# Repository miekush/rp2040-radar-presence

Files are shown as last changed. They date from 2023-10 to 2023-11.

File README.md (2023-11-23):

# RP2040 Radar Presence Sensor
RP2040/LD2410 based Radar Presence sensor

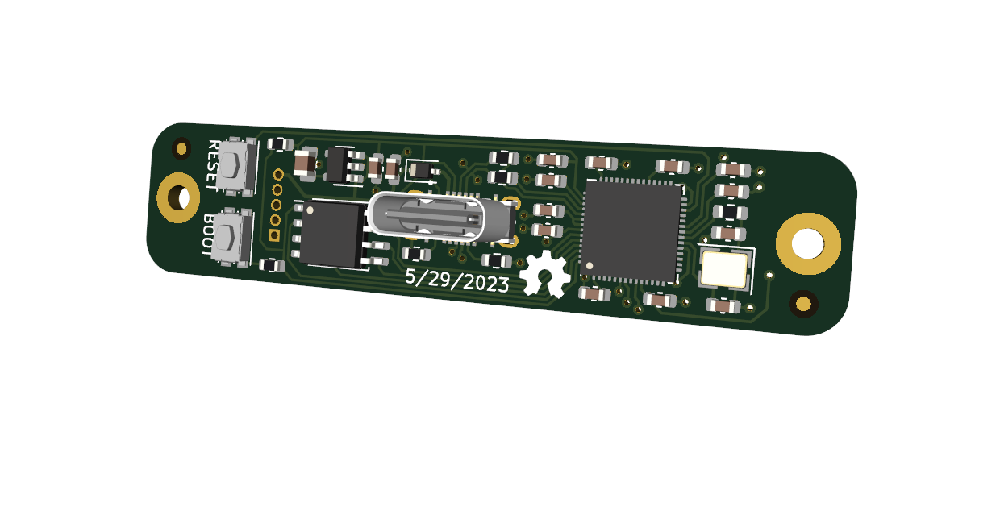
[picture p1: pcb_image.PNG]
Board Image


# Documentation

I created a short description for this project on Hackaday.io! See the project page [HERE](https://hackaday.io/project/193141-radar-halloween-candy-basket-light)!

# License

MKE supports the open source hardware community by sharing hardware design files freely on GitHub!

Please support MKE by purchasing products on [Tindie](https://www.tindie.com/stores/mkengineering/)!

Designed by Mike Kushnerik (miekush)

Licensed under [Creative Commons Attribution-ShareAlike CC BY-SA 4.0](http://creativecommons.org/licenses/by-sa/4.0/)

All text above must be included in any redistribution!

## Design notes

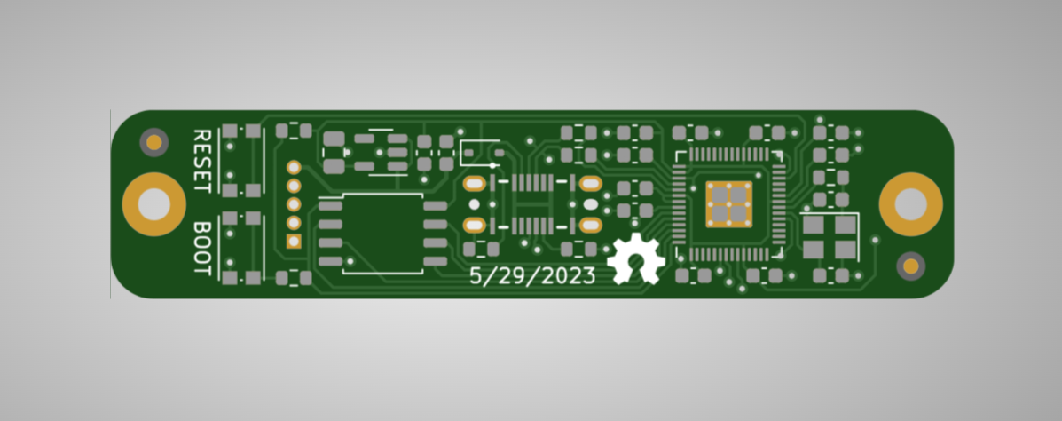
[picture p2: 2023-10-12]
pcb.PNG

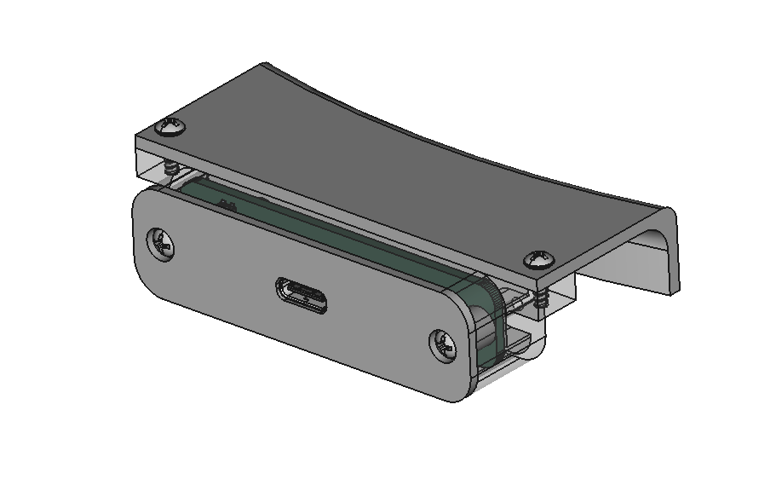
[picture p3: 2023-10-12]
enclosure/cad_image.PNG

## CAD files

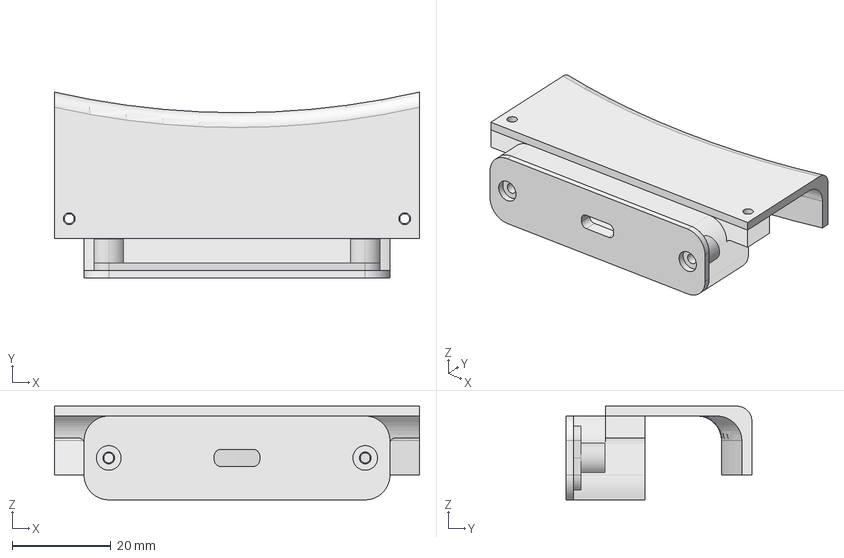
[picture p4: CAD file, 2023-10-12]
enclosure/radar_candy_bowl_light_v1.FCStd
74.0 x 37.7 x 19.0 mm
housing
cover
bracket

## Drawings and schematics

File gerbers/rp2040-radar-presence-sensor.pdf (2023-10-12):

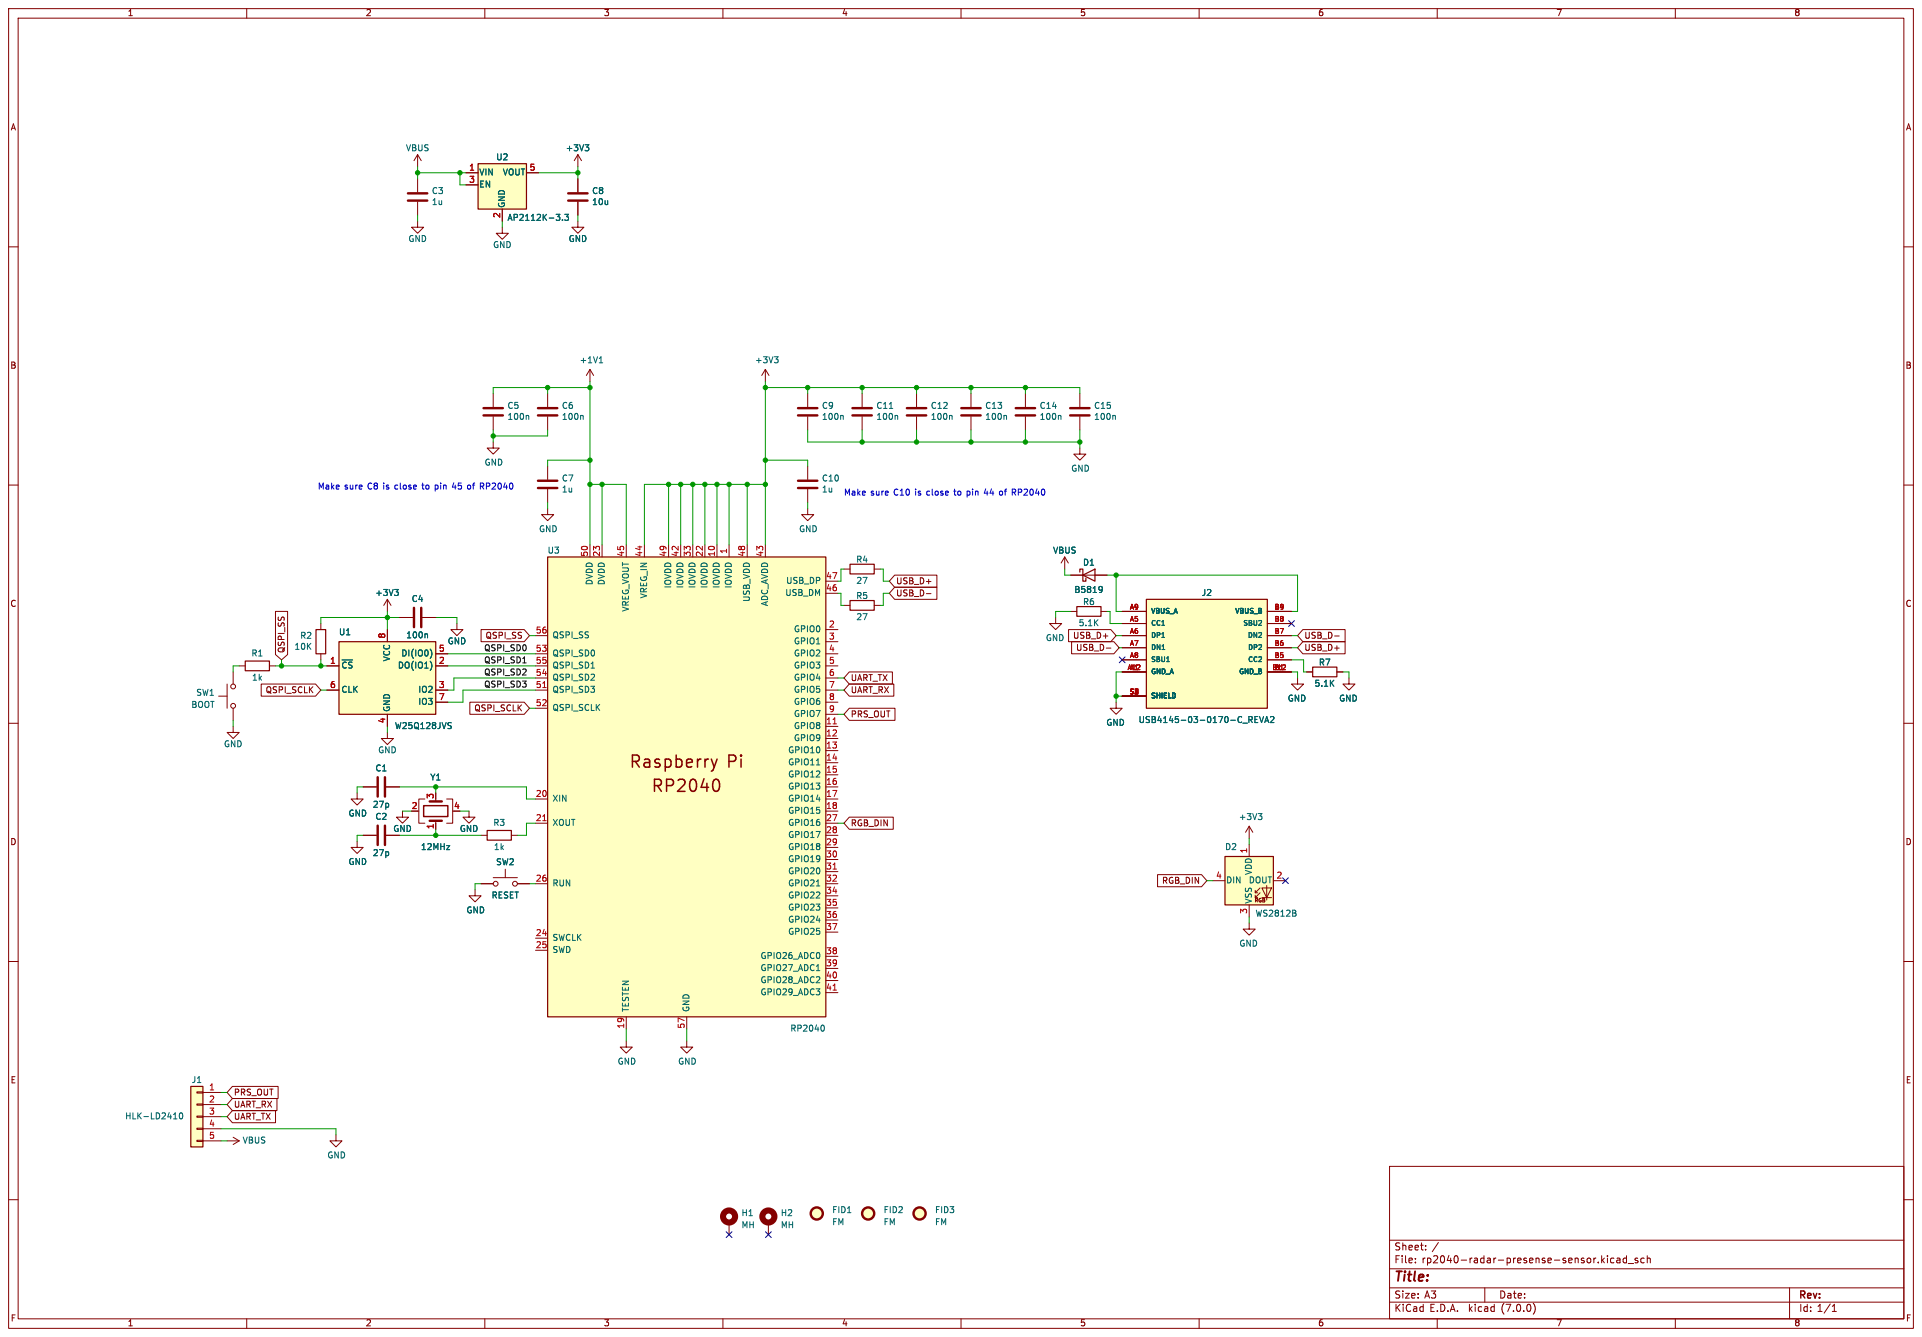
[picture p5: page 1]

1 IOVDD 10 GPIO8 11 GPIO9 12 GPIO10 13 GPIO11 14 GPIO12 15 GPIO13 16 GPIO14 17 GPIO15 18 TESTEN 19 GPIO0 2 XIN 20 XOUT 21 IOVDD 22 DVDD 23 SWCLK 24 SWD 25 RUN 26 GPIO16 27 GPIO17 28 GPIO18 29 GPIO1 3 GPIO19 30 GPIO20 31 GPIO21 32 IOVDD 33 GPIO22 34 GPIO23 35 GPIO24 36 GPIO25 37 GPIO26_ADC0 38 GPIO27_ADC1 39 GPIO2 4 GPIO28_ADC2 40 GPIO29_ADC3 41 IOVDD 42 ADC_AVDD 43 VREG_IN 44 VREG_VOUT 45 USB_DM 46 USB_DP 47 USB_VDD 48 IOVDD 49 GPIO3 5 DVDD 50 QSPI_SD3 51 QSPI_SCLK 52 QSPI_SD0 53 QSPI_SD2 54 QSPI_SD1 55 QSPI_SS 56 GND 57 GPIO4 6 GPIO5 7 GPIO6 8 GPIO7 9 U3 RP2040 GND
100n GND

Id: 1/1 Title: File: rp2040-radar-presense-sensor.kicad_sch Sheet: / GND

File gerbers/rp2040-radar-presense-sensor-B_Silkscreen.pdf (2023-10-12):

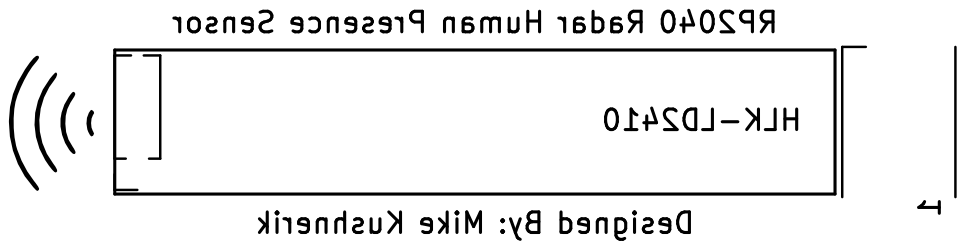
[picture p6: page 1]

HLK-LD2410 RP2040 Radar Human Presence Sensor Designed By: Mike Kushnerik 1

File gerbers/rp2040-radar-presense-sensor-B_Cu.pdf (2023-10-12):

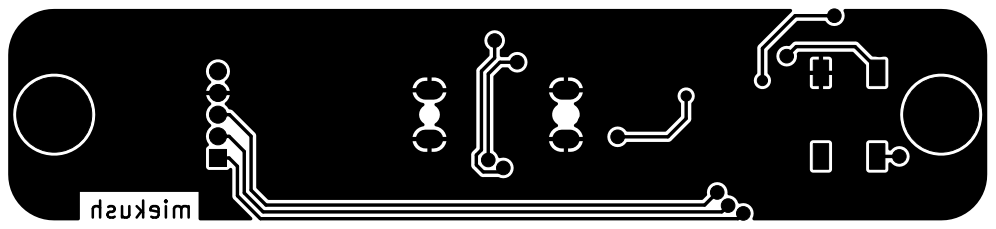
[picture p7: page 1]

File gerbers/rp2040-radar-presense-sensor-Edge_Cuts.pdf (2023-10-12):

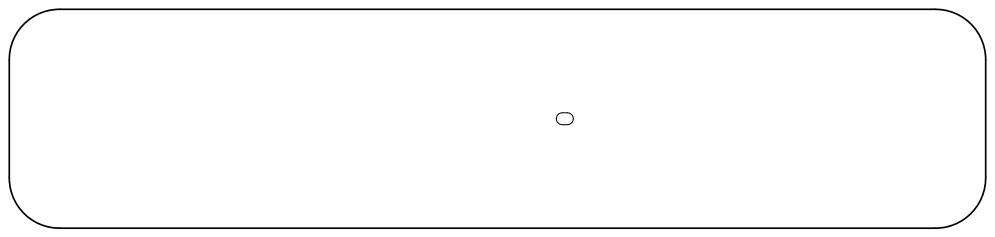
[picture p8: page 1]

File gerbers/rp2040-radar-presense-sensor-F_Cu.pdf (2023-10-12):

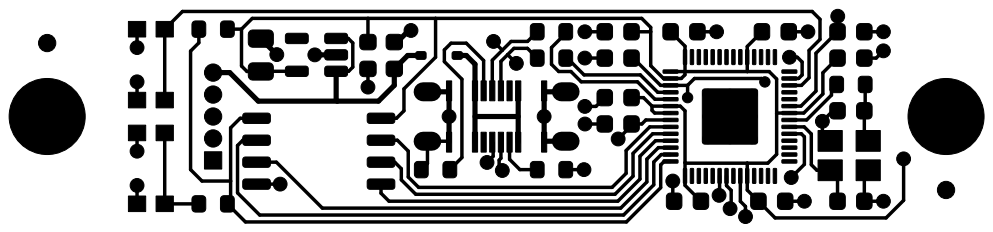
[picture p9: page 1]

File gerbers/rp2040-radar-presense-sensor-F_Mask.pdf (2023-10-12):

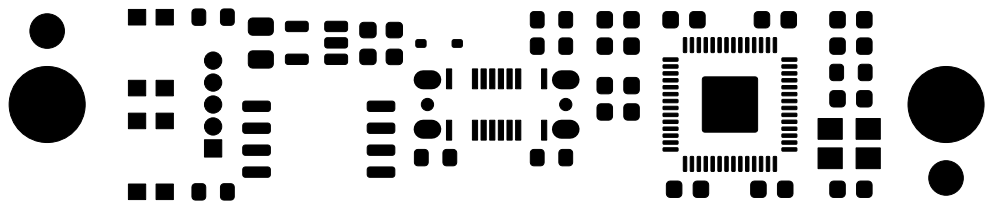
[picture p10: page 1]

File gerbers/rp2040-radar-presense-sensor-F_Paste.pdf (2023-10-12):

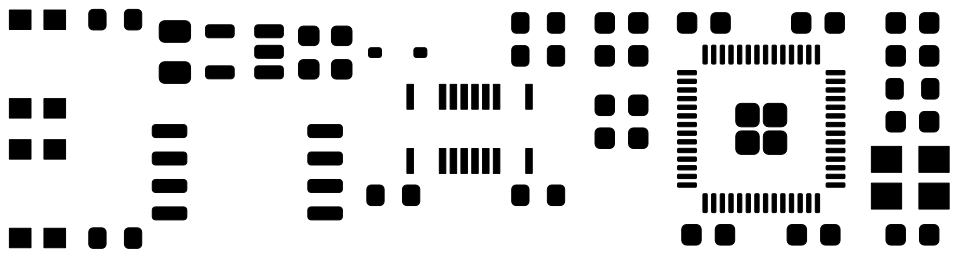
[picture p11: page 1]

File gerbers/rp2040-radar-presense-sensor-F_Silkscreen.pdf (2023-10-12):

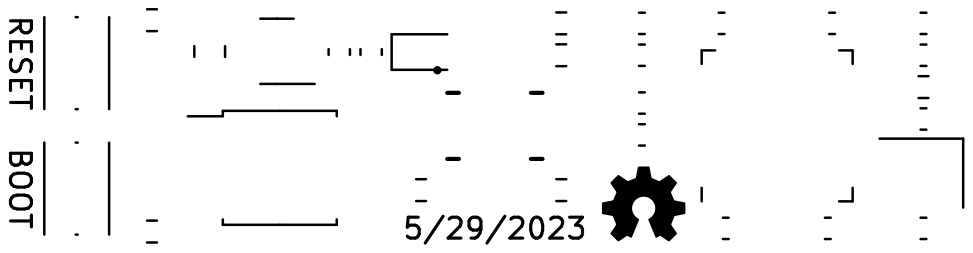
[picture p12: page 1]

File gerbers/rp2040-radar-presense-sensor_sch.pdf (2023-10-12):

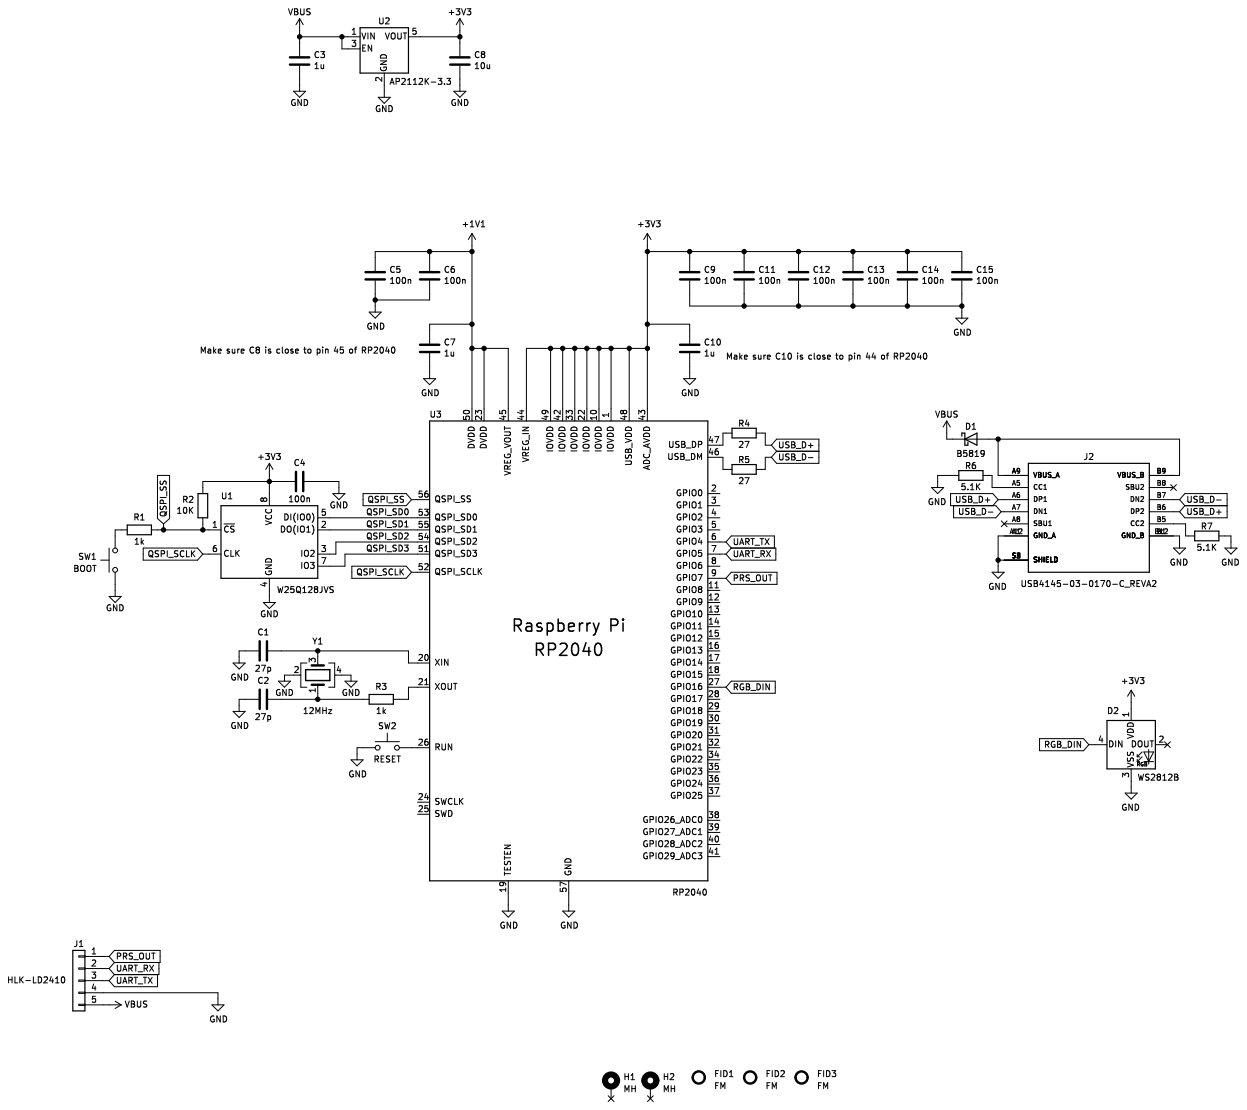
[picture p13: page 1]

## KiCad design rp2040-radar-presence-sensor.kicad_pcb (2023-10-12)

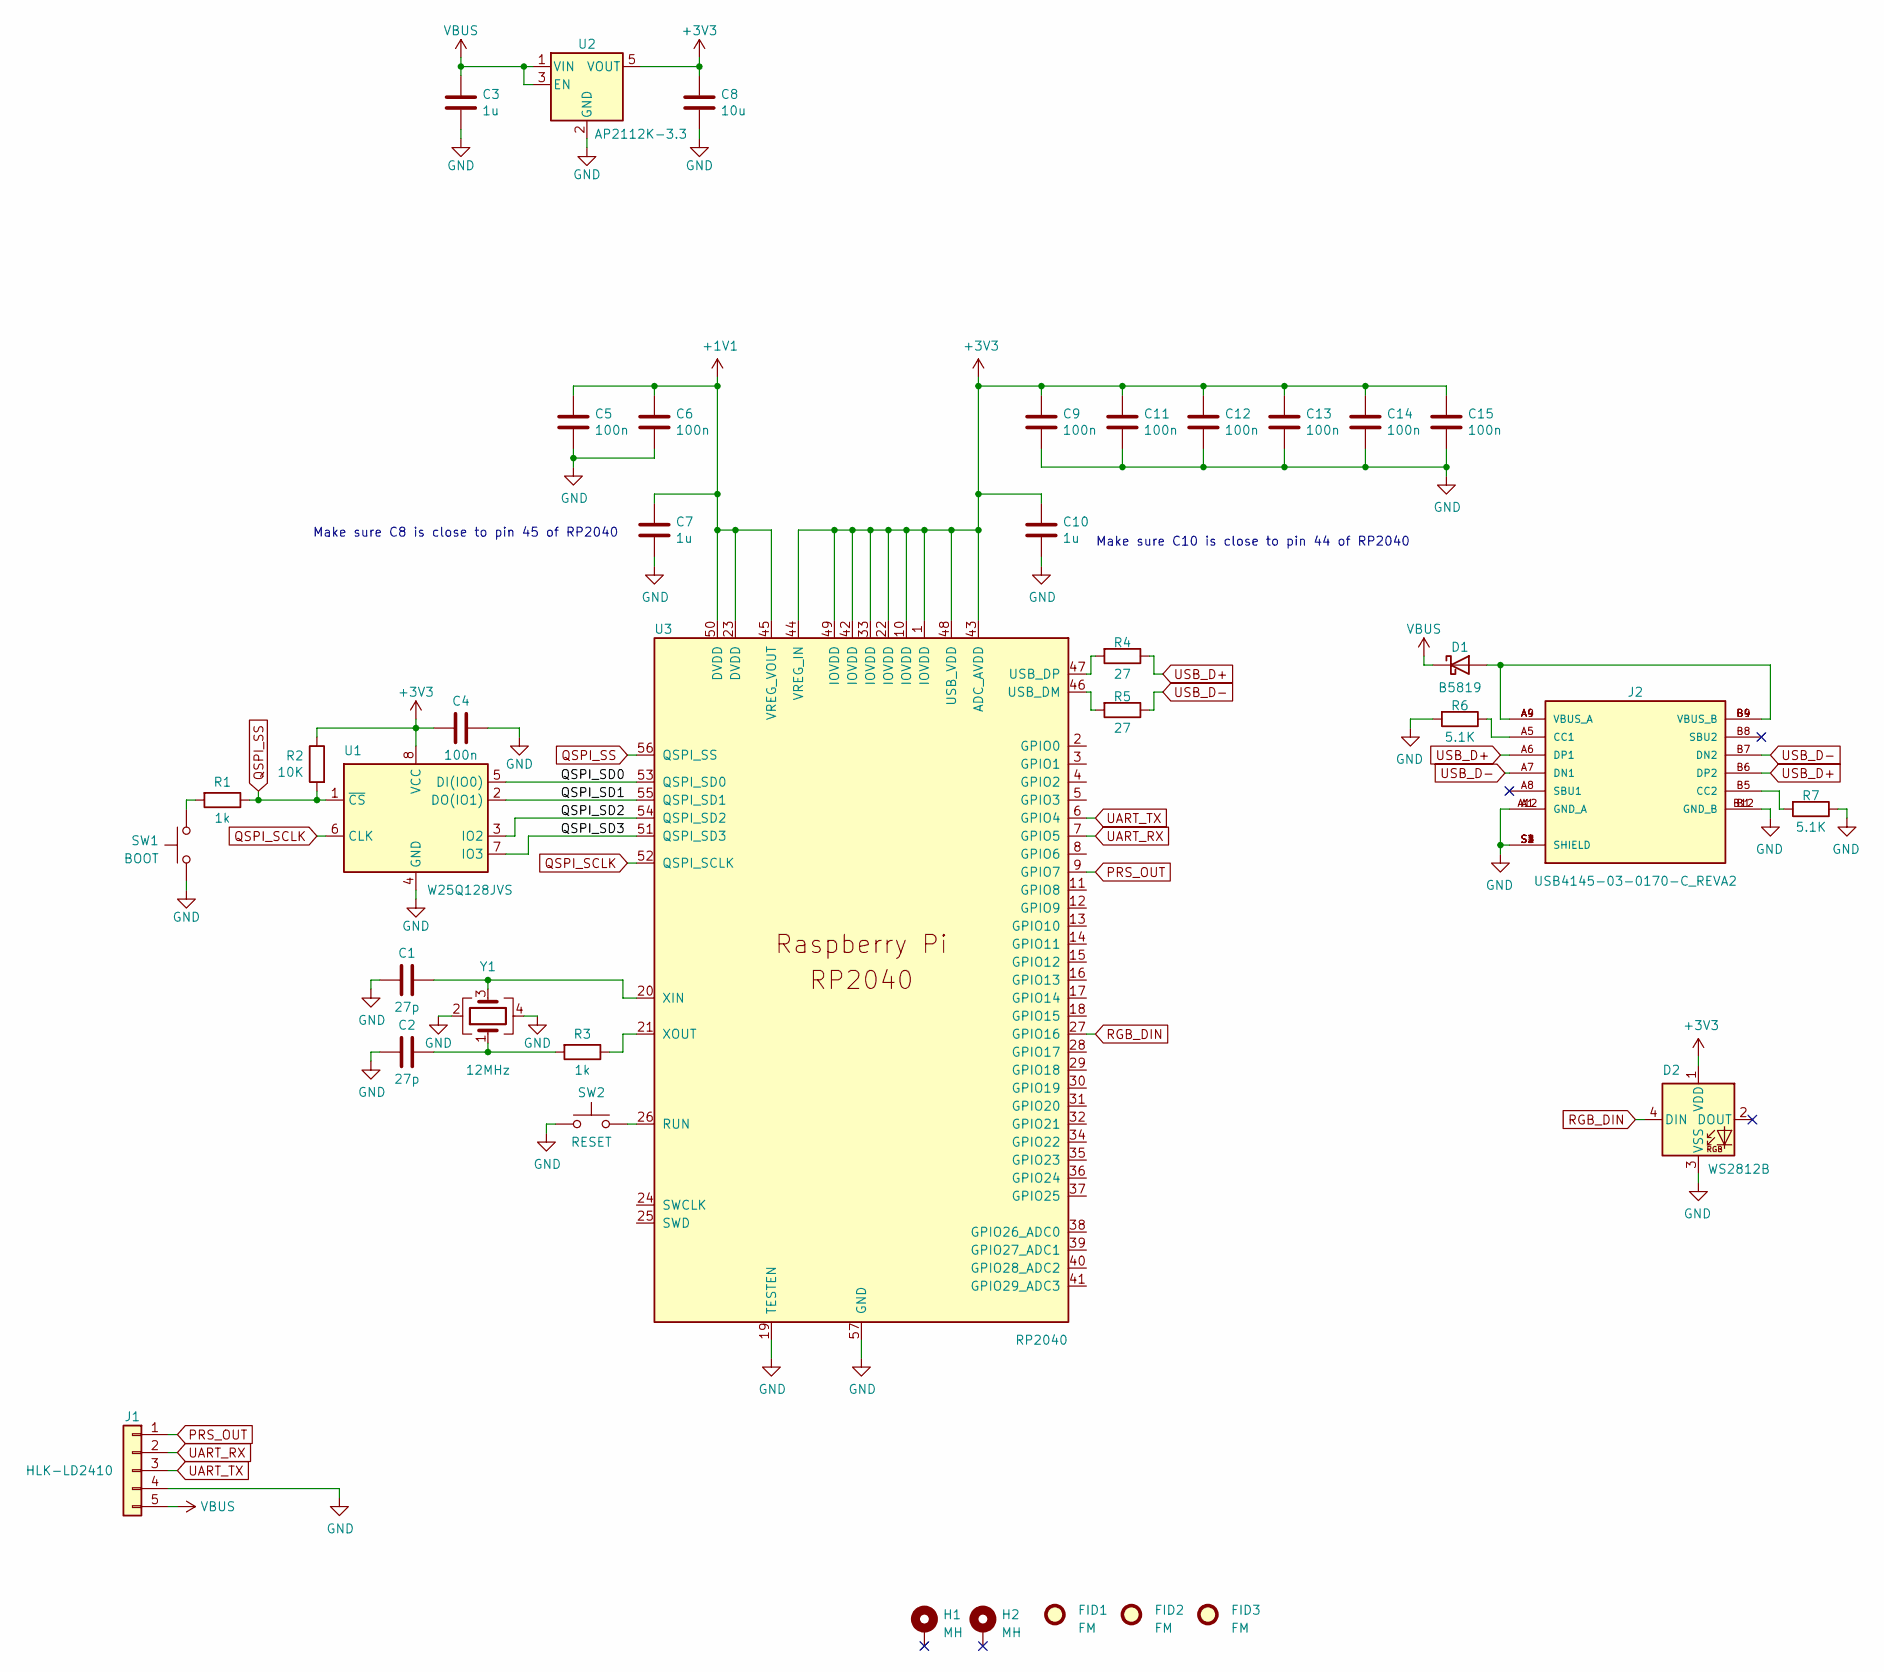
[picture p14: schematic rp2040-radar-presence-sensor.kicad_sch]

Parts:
C1, C2: 27p; C_0603_1608Metric
C3, C7, C10: 1u; C_0603_1608Metric
C4, C5, C6, C9, C11, C12, C13, C14, C15: 100n; C_0603_1608Metric
C8: 10u; C_0805_2012Metric
D1: B5819; D_SOD-323
D2: WS2812B; LED_WS2812B_PLCC4_5.0x5.0mm_P3.2mm
FID1, FID2, FID3: FM; Fiducial_1mm_Mask2mm
H1, H2: MH; MountingHole_2.2mm_M2_Pad
J1: HLK-LD2410; PinHeader_1x05_P1.27mm_Vertical
J2: USB4145-03-0170-C_REVA2; GCT_USB4145-03-0170-C_REVA2; PARTREV A2
R1, R3: 1k; R_0603_1608Metric
R2: 10K; R_0603_1608Metric
R4, R5: 27; R_0603_1608Metric
R6, R7: 5.1K; R_0603_1608Metric
SW1: BOOT; SW_Push_1P1T_NO_CK_KMR2
SW2: RESET; SW_Push_1P1T_NO_CK_KMR2
U1: W25Q128JVS; SOIC-8_5.23x5.23mm_P1.27mm
U2: AP2112K-3.3; SOT-23-5
U3: RP2040; RP2040-QFN-56
Y1: 12MHz; Crystal_SMD_Abracon_ABM8G-4Pin_3.2x2.5mm

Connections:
+1V1: C5.1, C6.1, C7.1, U3.23 (DVDD), U3.45 (VREG_VOUT), U3.50 (DVDD)
+3V3: C4.1, C8.1, C9.1, C10.1, C11.1, C12.1, C13.1, C14.1, C15.1, D2.1 (VDD), R2.1, U1.8 (VCC), U2.5 (VOUT), U3.1 (IOVDD), U3.10 (IOVDD), U3.22 (IOVDD), U3.33 (IOVDD), U3.42 (IOVDD), U3.43 (ADC_AVDD), U3.44 (VREG_IN), U3.48 (USB_VDD), U3.49 (IOVDD)
/QSPI_SD0: U1.5 (DI(IO0)), U3.53 (QSPI_SD0)
/QSPI_SD1: U1.2 (DO(IO1)), U3.55 (QSPI_SD1)
/QSPI_SD2: U1.3 (IO2), U3.54 (QSPI_SD2)
/QSPI_SD3: U1.7 (IO3), U3.51 (QSPI_SD3)
GND: C1.2, C2.2, C3.2, C4.2, C5.2, C6.2, C7.2, C8.2, C9.2, C10.2, C11.2, C12.2, C13.2, C14.2, C15.2, D2.3 (VSS), J1.4, J2.A1 (GND_A), J2.A12 (GND_A), J2.B1 (GND_B), J2.B12 (GND_B), J2.S1 (SHIELD), J2.S2 (SHIELD), J2.S3 (SHIELD), J2.S4 (SHIELD), R6.2, R7.1, SW1.1, SW2.1, U1.4 (GND), U2.2 (GND), U3.19 (TESTEN), U3.57 (GND), Y1.2, Y1.4
unnamed: C2.1, R3.2, Y1.1
unnamed: D1.2 (A), J2.A4 (VBUS_A), J2.A9 (VBUS_A), J2.B4 (VBUS_B), J2.B9 (VBUS_B)
unnamed: J2.A5 (CC1), R6.1
unnamed: J2.B5 (CC2), R7.2
unnamed: R1.2, SW1.2
unnamed: SW2.2, U3.26 (RUN)
unnamed: R5.2, U3.46 (USB_DM)
unnamed: R4.2, U3.47 (USB_DP)
unnamed: C1.1, U3.20 (XIN), Y1.3
unnamed: R3.1, U3.21 (XOUT)
PRS_OUT: J1.1, U3.9 (GPIO7)
QSPI_SCLK: U1.6 (CLK), U3.52 (QSPI_SCLK)
QSPI_SS: R1.1, R2.2, U1.1 (~CS), U3.56 (QSPI_SS)
RGB_DIN: D2.4 (DIN), U3.27 (GPIO16)
UART_RX: J1.2, U3.7 (GPIO5)
UART_TX: J1.3, U3.6 (GPIO4)
USB_D+: J2.A6 (DP1), J2.B6 (DP2), R4.1
USB_D-: J2.A7 (DN1), J2.B7 (DN2), R5.1
VBUS: C3.1, D1.1 (K), J1.5, U2.1 (VIN), U2.3 (EN)

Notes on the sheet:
Make sure C8 is close to pin 45 of RP2040
Make sure C10 is close to pin 44 of RP2040

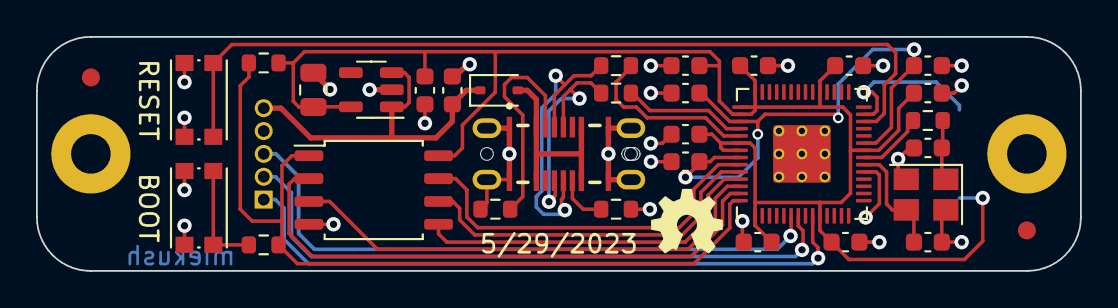
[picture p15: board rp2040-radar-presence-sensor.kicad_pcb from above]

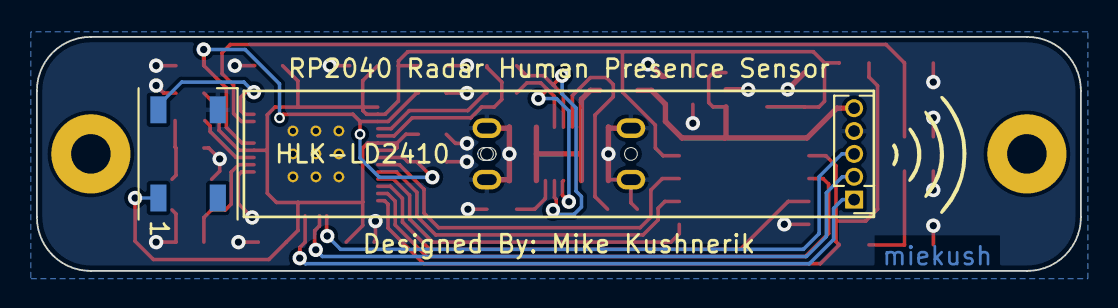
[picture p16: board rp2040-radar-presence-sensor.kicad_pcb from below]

Board: 2 copper layers, 58.0 x 13.0 mm, 36 parts (2 on the bottom side), 26 nets.

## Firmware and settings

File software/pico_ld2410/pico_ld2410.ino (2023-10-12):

#include <Adafruit_NeoPixel.h>

//define pins
#define RGB_PIN           16
#define TX_PIN            4
#define RX_PIN            5

//define parameters
#define NUM_SAMPLES       5
#define DISTANCE_THRES_1  120
#define DISTANCE_THRES_2  200

//init rgb neopixel
Adafruit_NeoPixel rgb(1, RGB_PIN, NEO_GRB + NEO_KHZ800);

uint8_t data[17];
uint8_t sampleCount=0;
uint16_t distanceSum=0;
uint8_t detectionSum=0;

bool averageDetection=false;
uint16_t averageDistance=0;

uint16_t targetDistance[NUM_SAMPLES];
uint8_t targetDetection[NUM_SAMPLES];

bool dataReady = false;

//debug modes
bool serialDebugBasic=false;
bool serialDebugAdvanced=false;

void setup()
{
  //debug output
  if(serialDebugBasic || serialDebugAdvanced)
  {
    Serial.begin(9600);
  }

  //init uart for sensor
  Serial2.setTX(TX_PIN);
  Serial2.setRX(RX_PIN);
  Serial2.begin(256000);

  //init rgb
  rgb.begin();
  rgb.clear();
}

void loop()
{
  //take sample
  readSensor();

  //check if samples complete
  if(dataReady)
  {
    detectionSum=0;
    distanceSum=0;

    for(int i=0; i<NUM_SAMPLES; i++)
    {
      detectionSum += targetDetection[i];
      distanceSum += targetDistance[i];
    }
    //take average
    averageDetection = detectionSum / NUM_SAMPLES;
    averageDistance = distanceSum / NUM_SAMPLES;

    //print distance info to terminal
    if(serialDebugBasic || serialDebugAdvanced)
    {
      Serial.print("SUM: ");
      Serial.print(distanceSum);
      Serial.print(", ");
      Serial.print("AVG: ");
      Serial.print(averageDistance);

      if(!serialDebugAdvanced)
      {
        Serial.println("");
      }
    }    

    //check for target
    if(averageDetection && (averageDistance < DISTANCE_THRES_1))
    {
      rgb.setPixelColor(0, rgb.Color(0, 255, 0));
      rgb.show();
    }
    else if(averageDetection && (averageDistance < DISTANCE_THRES_2))
    {
      rgb.setPixelColor(0, rgb.Color(255, 165, 0));
      rgb.show();
    }
    else
    {
      rgb.setPixelColor(0, rgb.Color(0, 0, 0));
      rgb.show();    
    }

    dataReady=false;
  }
}

void readSensor(void)
{
  if(Serial2.available())
  {
    uint8_t byte = Serial2.read();

    //check for EOF
    if(byte == 0xF5)
    {
      //read frame
      Serial2.readBytes(data, 17);

      //extract detection signal and distance signal
      targetDetection[sampleCount] = data[8];
      targetDistance[sampleCount] = (data[9] | (data[10] << 8));
      //increment sample count
      sampleCount++;

      //samples complete, ready to average
      if(sampleCount>(NUM_SAMPLES-1))
      {
        dataReady=true;
        sampleCount=0;
      }

      //print raw frame for debugging
      if(serialDebugAdvanced)
      {
        Serial.print("DATA: ");
        for(int i=4; i<17; i++)
        {
          Serial.printf("%02x", data[i]);
          Serial.print(" ");
        }
        Serial.println("");
      }
    }
  }
}
